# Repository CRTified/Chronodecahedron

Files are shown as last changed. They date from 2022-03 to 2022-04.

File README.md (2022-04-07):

# Chronodecahedron

 
 

https://esphome.io/ powered physical time-tracking dodecahedron.

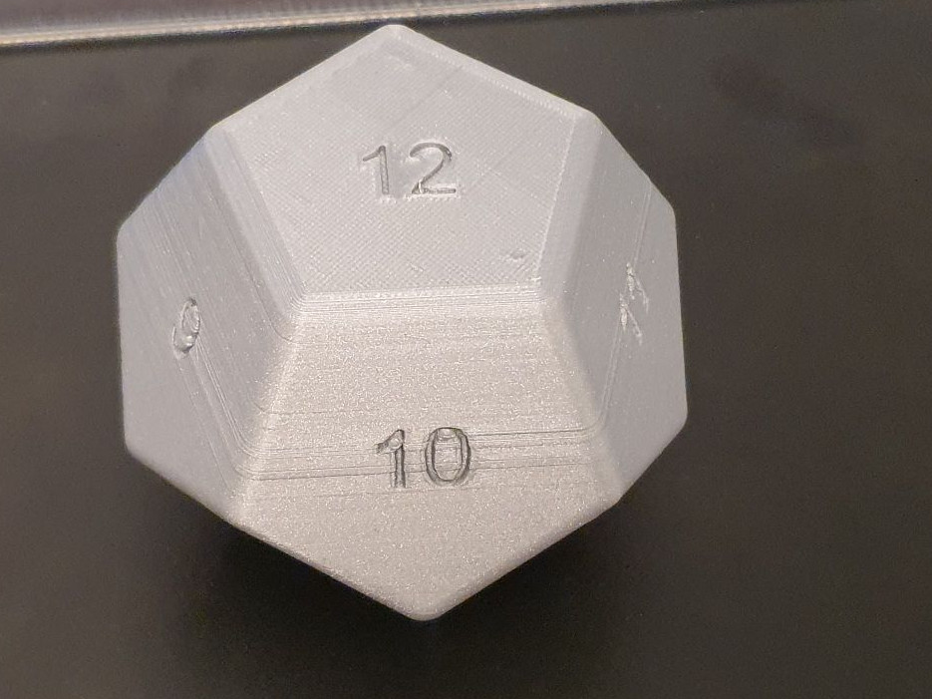
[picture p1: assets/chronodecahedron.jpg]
Chronodecahedron


## Licensing

 - [AGPL-3.0 or later](./LICENSE.AGPL-3.0-or-later) applies to the code and configuration `configuration.yaml`
 - [CC-BY-NC-4.0](./LICENSE.CC-BY-NC-4.0) applies to the 3D-model, description and other support material

## Project is WIP, but close to completion

Documentation is lacking at some points, but this is personally not a high priority.
The design is mostly settled, but might get some minor touchups.
Software might need some improvements, especially for keeping a usage history on
the ESP. Right now, this needs to be done manually.

## What is this?

This device is a physical time-tracking device to easily track how long you work on what.

It consists of a 3d-printed dodecahedron (12 sided platonic solid) and uses an 
accelerometer to detect which side faces up.

By using [esphome](https://esphome.io) as a platform, it is then able to expose 
the detected side as a sensor over MQTT or other protocols.

Check out [the model on a360.co](https://a360.co/3KxAjle). The `STL` and `f3z` are available in this repo.

### Use-Cases

 - Tracking time for projects (E.g. freelancers that switch between projects)
 - Use as scene-selector in home automation setups

Feel free to open PRs to extend this list :)

## What do I need?

### Tools

 - Soldering Iron
 - Desoldering tools
   - Pump, wick or whatever you are able to use
 - 3D Printer
 
### Parts

| Name | Pcs | Note |
|---|-----|---|
| **Prints** | | |
| Printed `hull.stl` | 1 | Use your preferred color+material |
| Printed `base.stl` | 1 | |
| **Mechanical** | | |
| M3 threaded inserts | 2 | Optional, depending on tolerances |
| M3x8 screws | 2 | Can be shorter |
| M2 threaded inserts | 2 | Recommended |
| M2x8 screws | 2 | |
| Double-sided tape | | |
| **Electrical** | | |
| Lolin32 Lite | 1 | |
| GY-521 (MPU-6050 Accelerometer)  | 1 | |
| Resistor 200kΩ THT | 2 | Other large sizes fine, too(50kΩ-500kΩ) |
| Li-Ion battery (with protection) | 1 | |
| Jumper wire | | `GND`/`INT` conection |
| 6x2.54mm pin header | 1 | Direct connection of the GY-521 |
| Solder | | |

## Assembly

### 0) Sourcing

 - Source the parts on your own
 - Print the parts with whatever material you prefer

### 1) Threaded Inserts

 - Melt the two M3 inserts into the holes of the printed `hull.stl`
 - Melt the two M2 inserts into the two blind holes of the printed `base.stl`
 
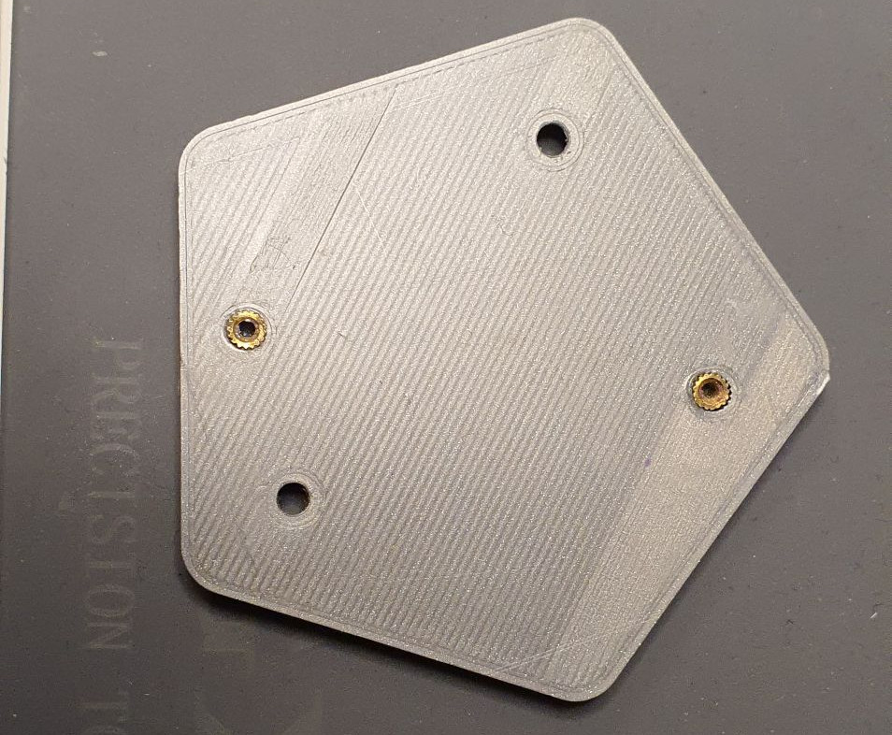
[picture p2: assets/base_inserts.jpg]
with threaded inserts


### 2) Electronics

 - (Optional: Desolder the JST-PH header for the battery)
 - Desolder the LED on the GY-521 (white component next to the x-axis silkscreen)
 
| Before | After |
|---|---|
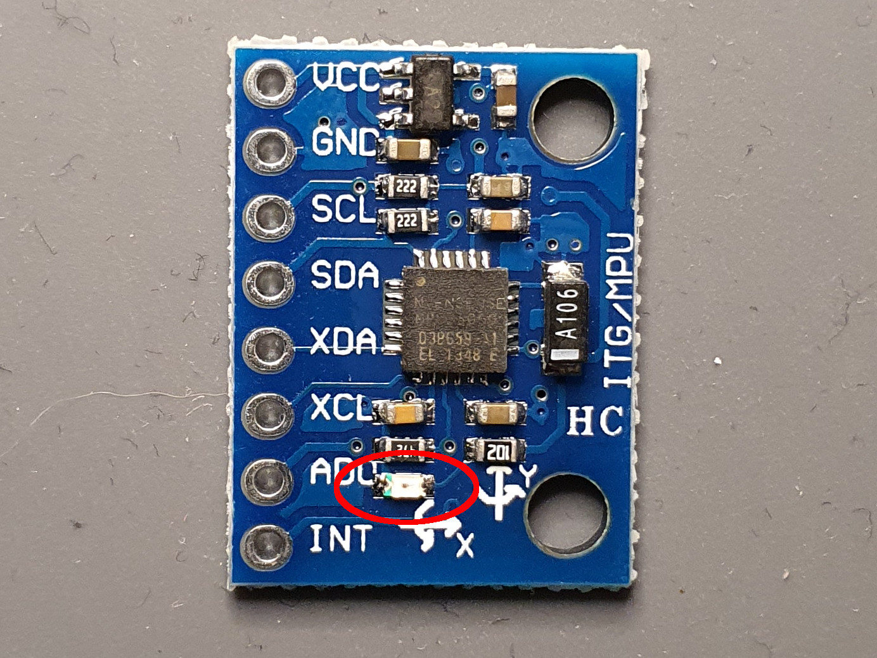
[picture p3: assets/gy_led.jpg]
GY-521, with the LED marked with a red circle LED to remove
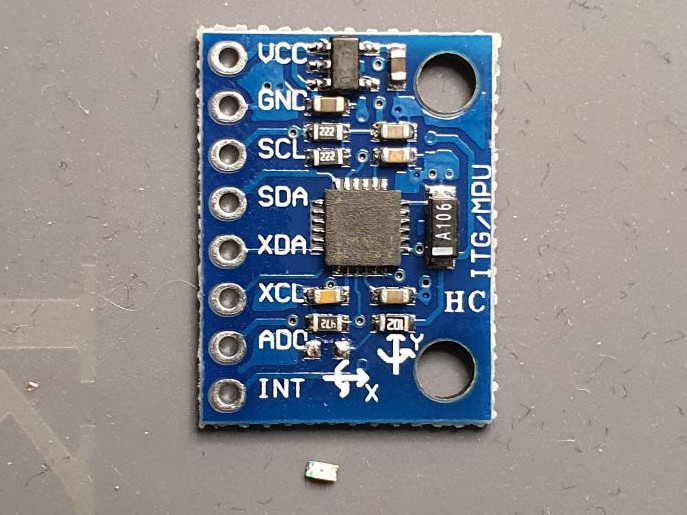
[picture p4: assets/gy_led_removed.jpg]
GY-521, with the LED next to it Removed LED
|  |  |
 
 - Stick both resistors with one lead through `GPIO33` and make a solder connection 
 - Solder the other lead of one of the 100kΩ resistors to the `+`-pad of the battery connector
 - Stick the other lead of the second resistor through `GND`, **but don't connect it yet**

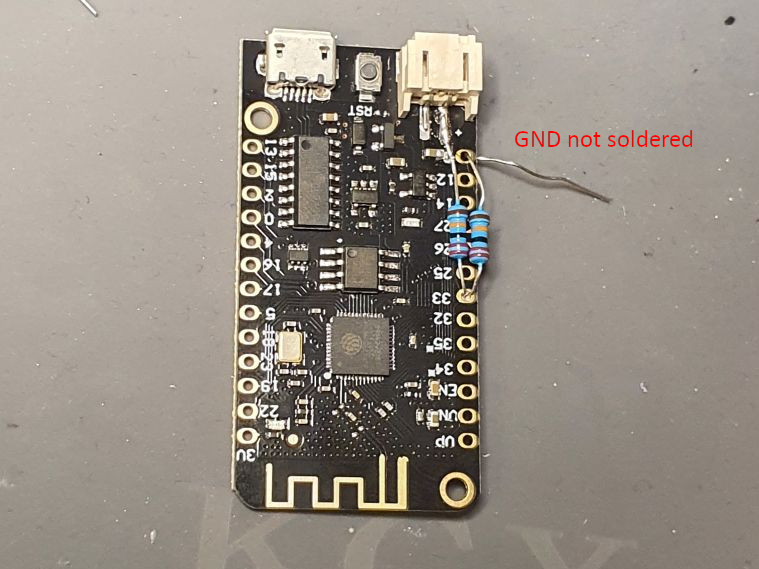
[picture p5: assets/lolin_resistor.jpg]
Lolin32 with Resistors and solder joint on Result


 - Put a piece of jumper wire (~6cm) through `GND`, now solder both the resistor and wire to GND
 - Solder another short piece of jumper wire (~2cm) on `INT`of the GY-521
 - Break away one of the pins of the pin header (you will have one single pin and a row of 5)
 - Solder the single pin on VCC of the GY-521, the remaining row on the pins `SCL` to `ADO`

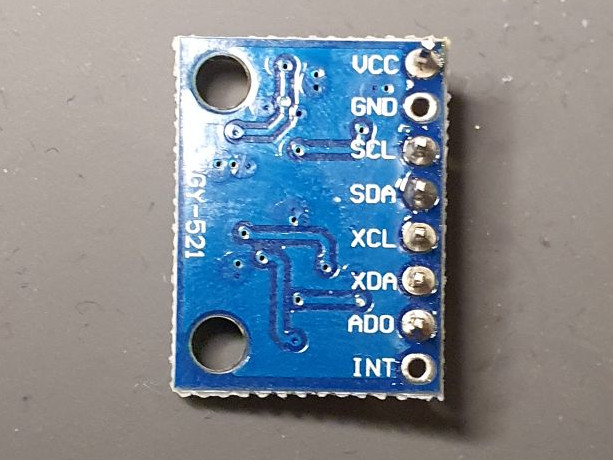
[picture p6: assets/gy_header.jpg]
GY-521 with pin row soldered to it Expected Result

 
 - Solder the other end of the long jumper wire to `GND` of the GY-521 (shown here without Board on the other side)
 
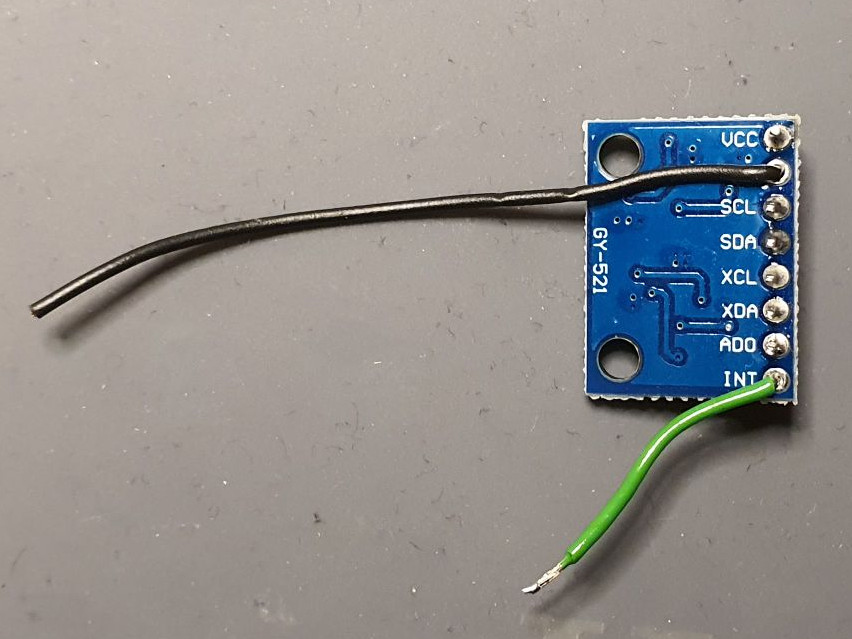
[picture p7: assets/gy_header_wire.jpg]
GY-521 with pin row and cables soldered to it Expected Result

 
 - Solder the GY-521 into `3V` to `GPIO17` of the Lolin32 Lite (This will leave `GPIO22` and `GPIO16` unconnected)
   - Make sure that it's relatively parallel to the Lolin32 Lite
 - Solder the other end of the short jumper wire to `GPIO13` of the Lolin32 Lite
 - Cut the pins on the back of the lolin32 flush

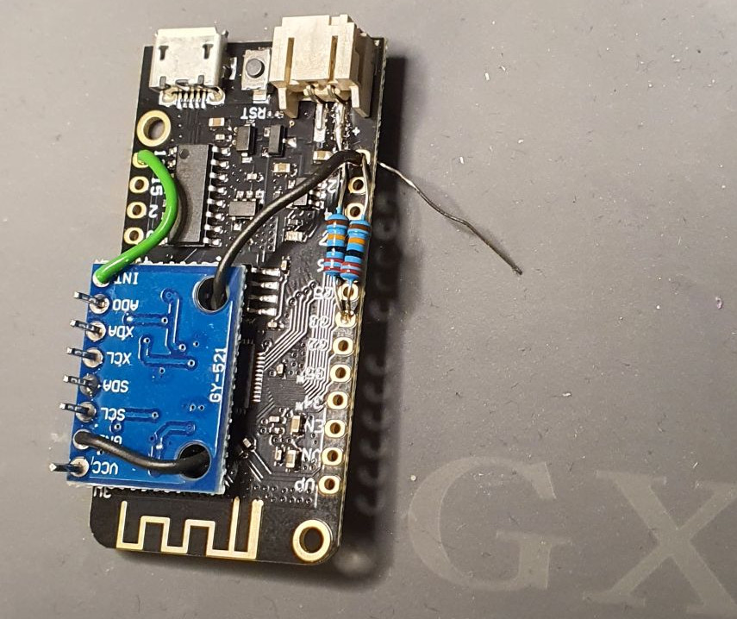
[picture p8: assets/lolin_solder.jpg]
Finished Lolin32 Lite Finished soldering


- (If you removed the JST-PH jack: Solder the battery to the pads))

### 3) Firmware

 - Modify the `yml`-files in the `esphome` directory to your needs (especially `secrets.yml`)
 - Connect the Lolin32
 - Run `esphome run chrono.yml` in that directory
 - Check that it works as expected (Side detection, battery level, battery charging)
   - The battery level might require fine-tuning. Measure the actual battery voltage level and compare it to the raw reported one.
 
### 4) Assembly

 - Use the M2 screws to attach the Lolin32 to the `base.stl`
 
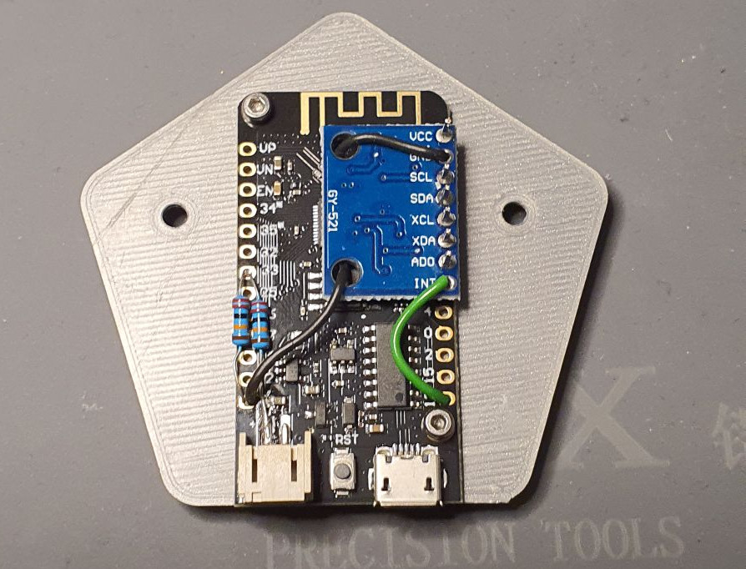
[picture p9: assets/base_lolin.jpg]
Base with Lolin32 lite attached Attached Lolin32 Lite

 
 - Use the double-sided tape to attach the Li-Ion battery to the inside of the `hull.stl`

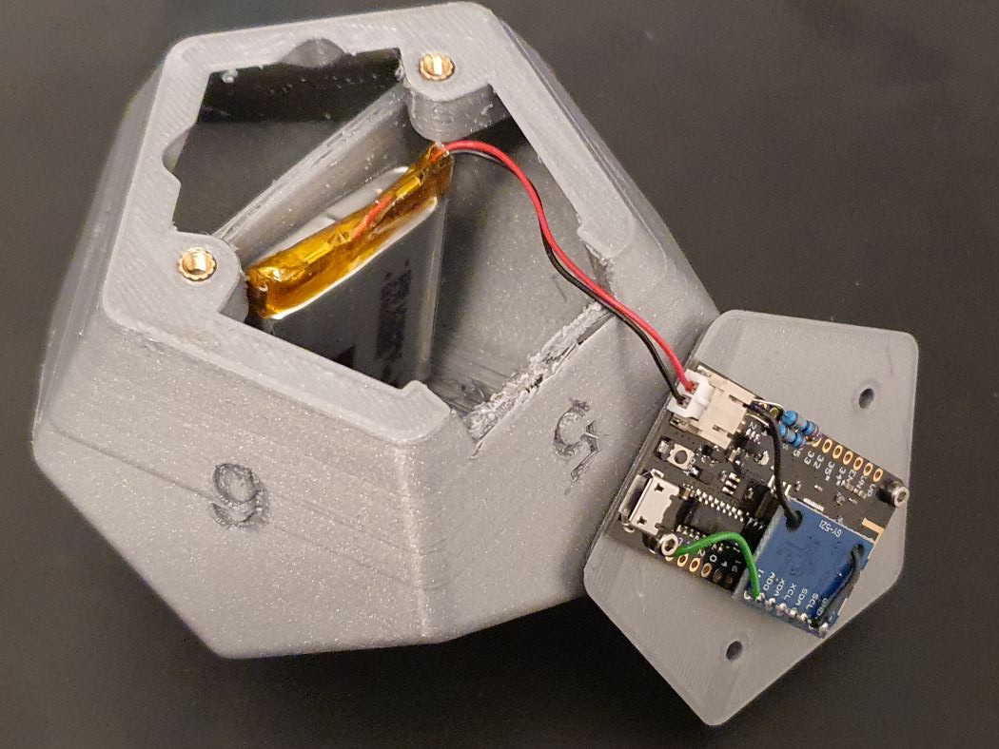
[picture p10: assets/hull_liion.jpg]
Hull with attached Li-Ion Battery Li-Ion taped to inner wall

 
 - Close the `base.stl` and the `hull.stl` and connect them with the M3 screws.

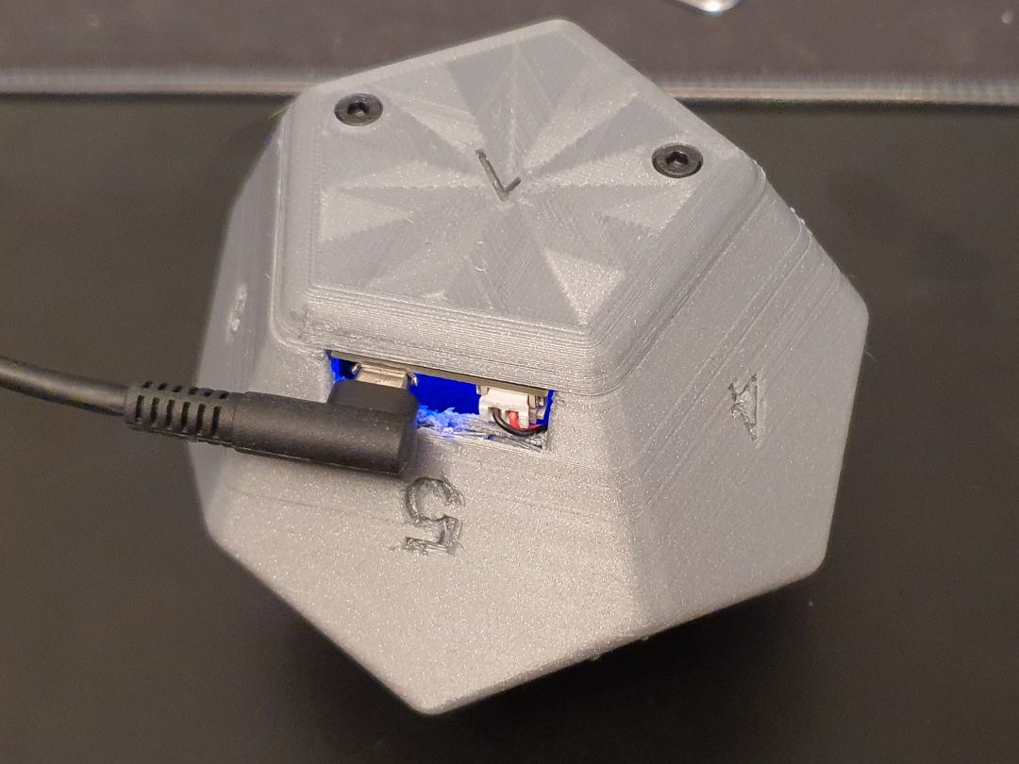
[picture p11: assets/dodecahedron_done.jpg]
Closed up Done


# `chronodecahedron-watcher`

`./src` contains a small python script that connects to MQTT and dumps the state
of the cube in a csv-like fashion (separator is ` ` - space), for easier 
processing in spreadsheets.

It can also be configured as a service on NixOS devices by:

 - Adding this repository as a flake input, e.g.:

```nix
    chronodecahedron = {
      url = "github:CRTified/Chronodecahedron";
	  # We only use basic library functions and packages, following your nixpkgs should be safe:
      inputs.nixpkgs.follows = "nixpkgs"; 
    };
```

 - Importing `chronodecahedron.nixosModule` as a module
 - Configuring the service under `services.chronodecahedron-watcher`, e.g.:

```nix
  services.chronodecahedron-watcher = {
    # Make it depend on mosquitto
    enable = config.services.mosquitto.enable;
    user = "chronos";
    group = "chronos";
	
    mqttServer = "localhost";
    mqttPort = 1883;
	
    mqttCredentialsFile = "/var/keys/mqttAuth";

    device = "timecube";
    logFile = "/root/chronodecahedron.csv";
  };
```

Note that credentials bypass the nix store and are stored in `/var/keys/mqttAuth`.
This file needs the following entries adapted to your need:
```
CHRONO_MQTT_USER=$mqttuser
CHRONO_MQTT_PASS=$mqttpass
```

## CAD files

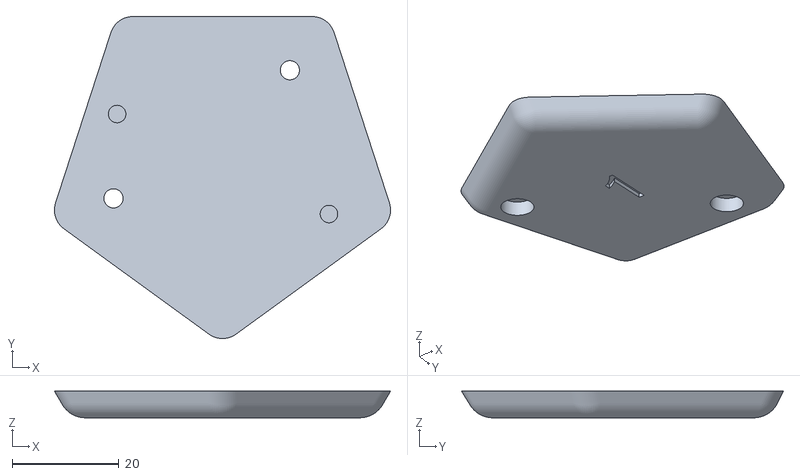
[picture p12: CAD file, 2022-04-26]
hardware/stl/base.stl
63.1 x 60.5 x 5.00

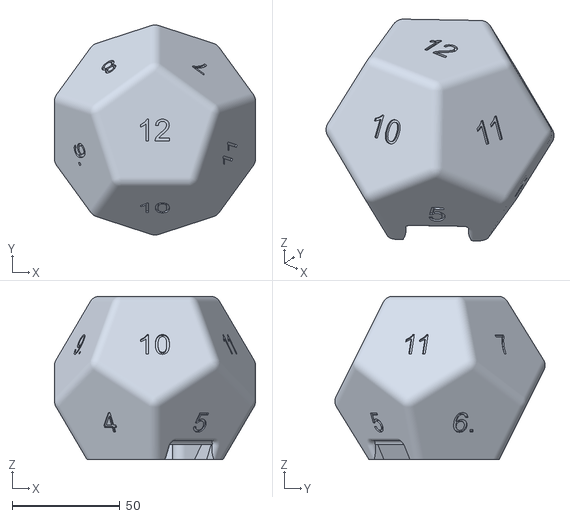
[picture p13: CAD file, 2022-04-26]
hardware/stl/hull.stl
93.3 x 97.6 x 75.9

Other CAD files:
hardware/model/Chronodekahedron.f3z

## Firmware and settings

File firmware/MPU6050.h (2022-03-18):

#include "esphome/core/component.h"
#include "esphome/components/sensor/sensor.h"
#include "esphome/components/i2c/i2c.h"


static const char *const TAG = "mpu6050";

const uint8_t MPU6050_REGISTER_WHO_AM_I = 0x75;
const uint8_t MPU6050_REGISTER_POWER_MANAGEMENT_1 = 0x6B;
const uint8_t MPU6050_REGISTER_INTERRUPTS= 0x38;
const uint8_t MPU6050_REGISTER_GYRO_CONFIG = 0x1B;
const uint8_t MPU6050_REGISTER_ACCEL_CONFIG = 0x1C;
const uint8_t MPU6050_REGISTER_ACCEL_XOUT_H = 0x3B;
const uint8_t MPU6050_CLOCK_SOURCE_X_GYRO = 0b001;
const uint8_t MPU6050_SCALE_2000_DPS = 0b11;
const float MPU6050_SCALE_DPS_PER_DIGIT_2000 = 0.060975f;
const uint8_t MPU6050_RANGE_2G = 0b00;
const float MPU6050_RANGE_PER_DIGIT_2G = 0.000061f;
const uint8_t MPU6050_BIT_SLEEP_ENABLED = 6;
const uint8_t MPU6050_BIT_TEMPERATURE_DISABLED = 3;
const float GRAVITY_EARTH = 9.80665f;

// Vectors calculated by ./misc/vector_calc.sage
const float FACES[12][4] = {
  // Remember: Rotation might be numerically imprecise
  /*  1 */ { +0.0000000, -0.0493718, +0.9987805 },
  /*  2 */ { -0.5257311, +0.7006446, +0.4823940 },
  /*  3 */ { +0.5257311, +0.7006446, +0.4823940 },
  /*  4 */ { +0.8506508, -0.2981359, +0.4330222 },
  /*  5 */ { +0.0000000, -0.9154162, +0.4025087 },
  /*  6 */ { -0.8506508, -0.2981359, +0.4330222 },
  /*  7 */ { -0.8506508, +0.2981359, -0.4330222 },
  /*  8 */ { +0.0000000, +0.9154162, -0.4025087 },
  /*  9 */ { +0.8506508, +0.2981359, -0.4330222 },
  /* 10 */ { +0.5257311, -0.7006446, -0.4823940 },
  /* 11 */ { -0.5257311, -0.7006446, -0.4823940 },
  /* 12 */ { +0.0000000, +0.0493718, -0.9987805 },
};

class MPU6050Component : public PollingComponent, public i2c::I2CDevice {
public:
  MPU6050Component() : PollingComponent(1000), I2CDevice() {};
  
  void setup() override {
    this->set_i2c_address( 0x68 );

    ESP_LOGCONFIG(TAG, "Setting up MPU6050...");
    uint8_t who_am_i;
    if (!this->read_byte(MPU6050_REGISTER_WHO_AM_I, &who_am_i) || who_am_i != 0x68) {
      ESP_LOGD(TAG, BYTE_TO_BINARY_PATTERN, BYTE_TO_BINARY(who_am_i));
      ESP_LOGV(TAG, "WHO AM I:" BYTE_TO_BINARY_PATTERN, BYTE_TO_BINARY(who_am_i));
      this->mark_failed();
      return;
    }

    ESP_LOGV(TAG, "  Setting up Power Management...");
    // Setup power management
    uint8_t power_management;
    if (!this->read_byte(MPU6050_REGISTER_POWER_MANAGEMENT_1, &power_management)) {
      this->mark_failed();
      return;
    }
    ESP_LOGV(TAG, "  Input power_management: 0b" BYTE_TO_BINARY_PATTERN, BYTE_TO_BINARY(power_management));
    power_management = 0;
    ESP_LOGV(TAG, "  Output power_management: 0b" BYTE_TO_BINARY_PATTERN, BYTE_TO_BINARY(power_management));
    if (!this->write_byte(MPU6050_REGISTER_POWER_MANAGEMENT_1, power_management)) {
      this->mark_failed();
      return;
    }
    
    
    ESP_LOGV(TAG, "  Setting up Gyro Config...");
    // Set scale - 2000DPS
    uint8_t gyro_config;
    if (!this->read_byte(MPU6050_REGISTER_GYRO_CONFIG, &gyro_config)) {
      this->mark_failed();
      return;
    }
    ESP_LOGV(TAG, "  Input gyro_config: 0b" BYTE_TO_BINARY_PATTERN, BYTE_TO_BINARY(gyro_config));
    gyro_config &= 0b11100111;
    gyro_config |= MPU6050_SCALE_2000_DPS << 3;
    ESP_LOGV(TAG, "  Output gyro_config: 0b" BYTE_TO_BINARY_PATTERN, BYTE_TO_BINARY(gyro_config));
    if (!this->write_byte(MPU6050_REGISTER_GYRO_CONFIG, gyro_config)) {
      this->mark_failed();
      return;
    }

    ESP_LOGV(TAG, "  Setting up Accel Config...");
    // Set range - 2G
    uint8_t accel_config;
    if (!this->read_byte(MPU6050_REGISTER_ACCEL_CONFIG, &accel_config)) {
      this->mark_failed();
      return;
    }
    ESP_LOGV(TAG, "    Input accel_config: 0b" BYTE_TO_BINARY_PATTERN, BYTE_TO_BINARY(accel_config));
    accel_config &= 0b11100111;
    accel_config |= (MPU6050_RANGE_2G << 3);
    ESP_LOGV(TAG, "    Output accel_config: 0b" BYTE_TO_BINARY_PATTERN, BYTE_TO_BINARY(accel_config));
    if (!this->write_byte(MPU6050_REGISTER_GYRO_CONFIG, gyro_config)) {
      this->mark_failed();
      return;
    }

    /*
      https://www.eluke.nl/2016/08/11/how-to-enable-motion-detection-interrupt-on-mpu6050/
     */
    ESP_LOGV(TAG, "  Setting up Motion Detection...");
    // if (!this->write_byte(0x68, 0x07)) { this->mark_failed(); return; }; // Reset foo
    if (!this->write_byte(0x37, 0x30)) { this->mark_failed(); return; }; // Active high, until any read
    if (!this->write_byte(0x1C, 0x04)) { this->mark_failed(); return; }; // 5Hz High Pass
    if (!this->write_byte(0x1F,  5)) { this->mark_failed(); return; }; // Motion Threshold 10 mg
    if (!this->write_byte(0x20,  10)) { this->mark_failed(); return; }; // 10ms movement for wakeup
    if (!this->write_byte(0x69, 0x15)) { this->mark_failed(); return; }; // Free-Fall and motion decrements to 1
    if (!this->write_byte(0x38, 0x40)) { this->mark_failed(); return; }; // Enable Motion Detection Interrupt
  }
  
  void dump_config() override {
    ESP_LOGCONFIG(TAG, "MPU6050:");
    LOG_I2C_DEVICE(this);
    if (this->is_failed()) {
      ESP_LOGE(TAG, "Communication with MPU6050 failed!");
    }
    LOG_UPDATE_INTERVAL(this);
    LOG_SENSOR("  ", "Acceleration X", this->accel_x_sensor_);
    LOG_SENSOR("  ", "Acceleration Y", this->accel_y_sensor_);
    LOG_SENSOR("  ", "Acceleration Z", this->accel_z_sensor_);
    LOG_SENSOR("  ", "Gyro X", this->gyro_x_sensor_);
    LOG_SENSOR("  ", "Gyro Y", this->gyro_y_sensor_);
    LOG_SENSOR("  ", "Gyro Z", this->gyro_z_sensor_);
    LOG_SENSOR("  ", "Temperature", this->temperature_sensor_);
    LOG_SENSOR("  ", "Face", this->face_sensor_);
  }

  void update() override {
    ESP_LOGV(TAG, "    Updating MPU6050...");
    uint16_t raw_data[7];
    if (!this->read_bytes_16(MPU6050_REGISTER_ACCEL_XOUT_H, raw_data, 7)) {
      this->status_set_warning();
      return;
    }
    auto *data = reinterpret_cast<int16_t *>(raw_data);

    float accel_x = data[0] * MPU6050_RANGE_PER_DIGIT_2G * GRAVITY_EARTH;
    float accel_y = data[1] * MPU6050_RANGE_PER_DIGIT_2G * GRAVITY_EARTH;
    float accel_z = data[2] * MPU6050_RANGE_PER_DIGIT_2G * GRAVITY_EARTH;

    float temperature = data[3] / 340.0f + 36.53f;

    float gyro_x = data[4] * MPU6050_SCALE_DPS_PER_DIGIT_2000;
    float gyro_y = data[5] * MPU6050_SCALE_DPS_PER_DIGIT_2000;
    float gyro_z = data[6] * MPU6050_SCALE_DPS_PER_DIGIT_2000;

    ESP_LOGD(TAG,
	     "Got accel={x=%.3f m/s², y=%.3f m/s², z=%.3f m/s²}, "
	     "gyro={x=%.3f °/s, y=%.3f °/s, z=%.3f °/s}, temp=%.3f°C",
	     accel_x, accel_y, accel_z, gyro_x, gyro_y, gyro_z, temperature);

    if (this->accel_x_sensor_ != nullptr)
      this->accel_x_sensor_->publish_state(accel_x);
    if (this->accel_y_sensor_ != nullptr)
      this->accel_y_sensor_->publish_state(accel_y);
    if (this->accel_z_sensor_ != nullptr)
      this->accel_z_sensor_->publish_state(accel_z);

    if (this->temperature_sensor_ != nullptr)
      this->temperature_sensor_->publish_state(temperature);
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

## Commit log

2022-03-18 doc: Add images of soldering steps for GY-521
2022-03-18 firmware: Reorganize code and filter
2022-03-19 hardware: Add STL and f3z
    [Chronodekahedron.f3z, base.stl, hull.stl]
2022-03-21 firmware: Use template sensor
2022-04-23 hardware: Make USB jack more accessible, add dots to 6,9
    [Chronodekahedron.f3z, base.stl, hull.stl]
2022-04-26 hardware: Make usable with threaded inserts with 5mm dia
    [Chronodekahedron.f3z, base.stl, hull.stl]

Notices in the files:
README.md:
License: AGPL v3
